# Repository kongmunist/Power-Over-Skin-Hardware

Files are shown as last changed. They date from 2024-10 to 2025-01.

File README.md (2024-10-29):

# Hi, welcome to the Power-over-Skin Repo

This repository contains the PCB files for the receiver board from the ACM UIST paper ["Power-over-Skin: Full-Body Wearables Powered By Intra-Body RF Energy"](https://dl.acm.org/doi/10.1145/3654777.3676394)

# BOM for receiver
You can assume all parts are generic unless mentioned below:

- R1-R7: Voltage setting resistors, should be 1% or better

- L2, L3: buck/boost inductors for the BQ25570. Should handle >200mA saturation current according to BQ25570 datasheet, but we're using low currents so you would probably get away with lower values. We used CB2518T100K and BRC2518T220K

- C4: Anything >100uF will do. I'm using the F950J107MPAAQ2, it is the only one that's quite so small, but it's also very DC-leaky

- L1: Should have a self-resonant frequency over 200 MHz in order to accomodate incoming square wave harmonics. 
- C9: Should be NP0, with a Vmax 10V or better

# Transmitter
In our experiments, we used a benchtop transmitter and a wearable one to generate 40 MHz square waves. These were passed through an impedance-matching network to couple into the body. The values we used were: first 20pF in series, then 820nH to ground. 

The 20pF should be NP0 with a voltage rating higher than the 40MHz you're sending into it. We used this inductor [(L-15FR82JV4E)](https://www.mouser.com/ProductDetail/Johanson-Technology/L-15FR82JV4E?qs=N%252Bgu1CRRfTPf9IhMOTDbHA%3D%3D) but anything with a self-resonant frequency >200 MHz should work. 

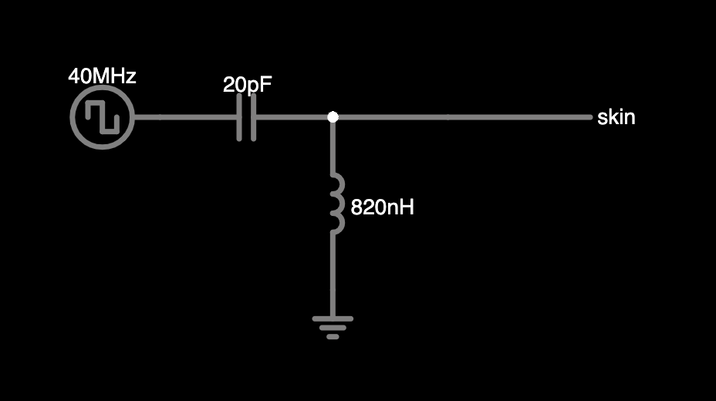
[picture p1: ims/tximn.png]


# Matching for other frequencies
The RF component values are all tuned for 40 MHz and human skin impedance — if you'd like to use another frequency, you'll have to resimulate the circuit. 

# Further questions?
Feel free to email Andy with any questions!

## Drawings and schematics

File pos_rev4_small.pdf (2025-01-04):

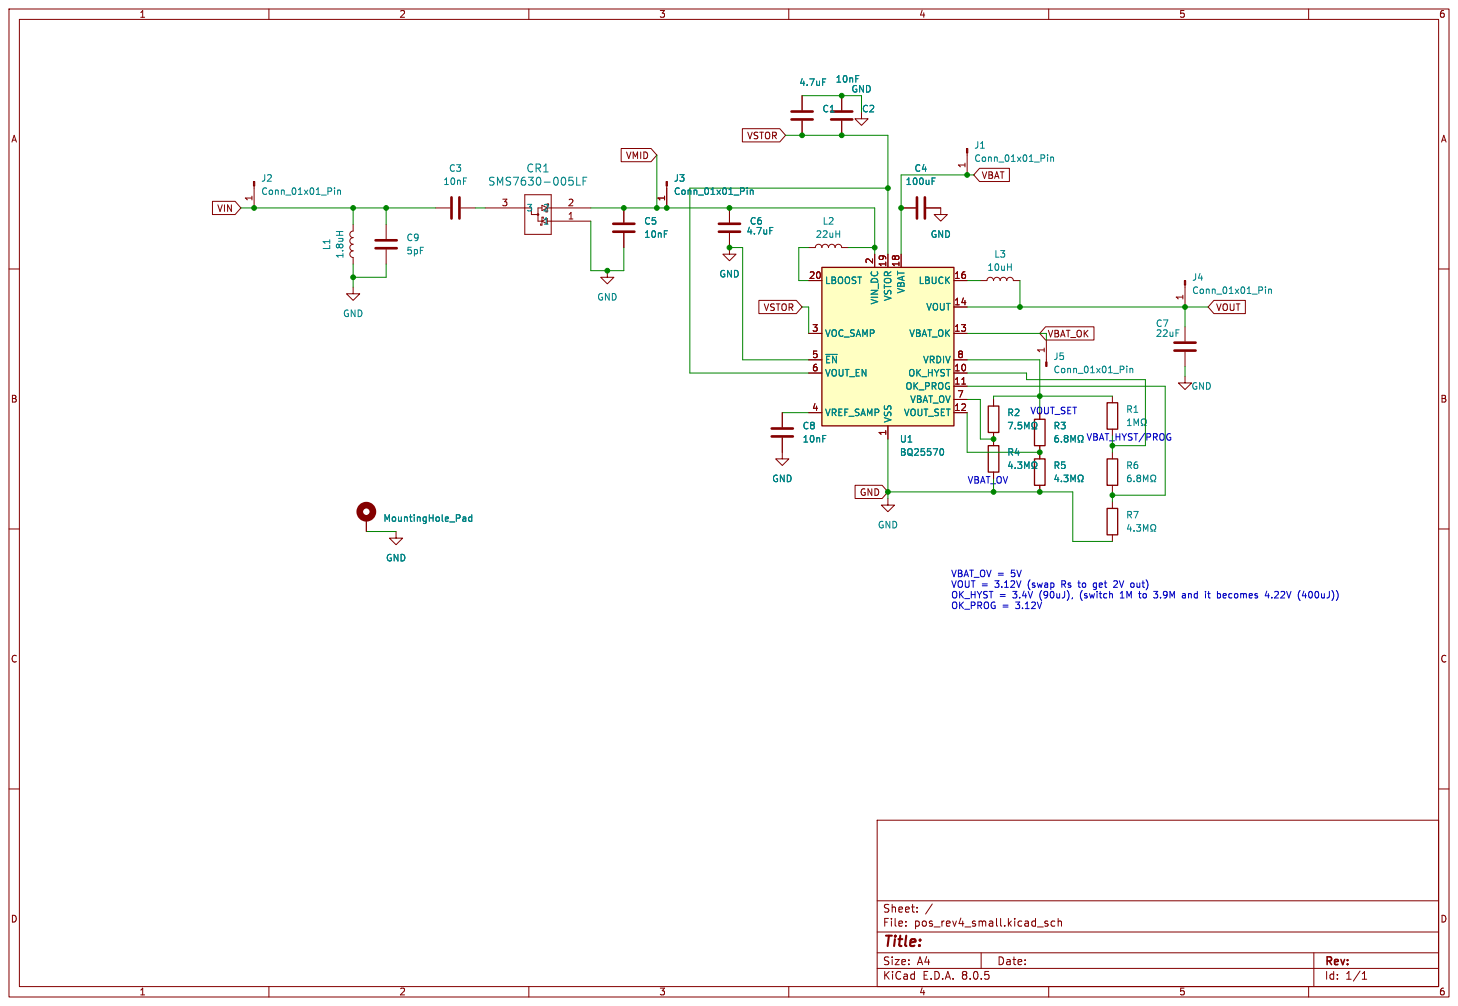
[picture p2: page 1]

Id: 1/1 Title: File: pos_rev4_small.kicad_sch Sheet: /

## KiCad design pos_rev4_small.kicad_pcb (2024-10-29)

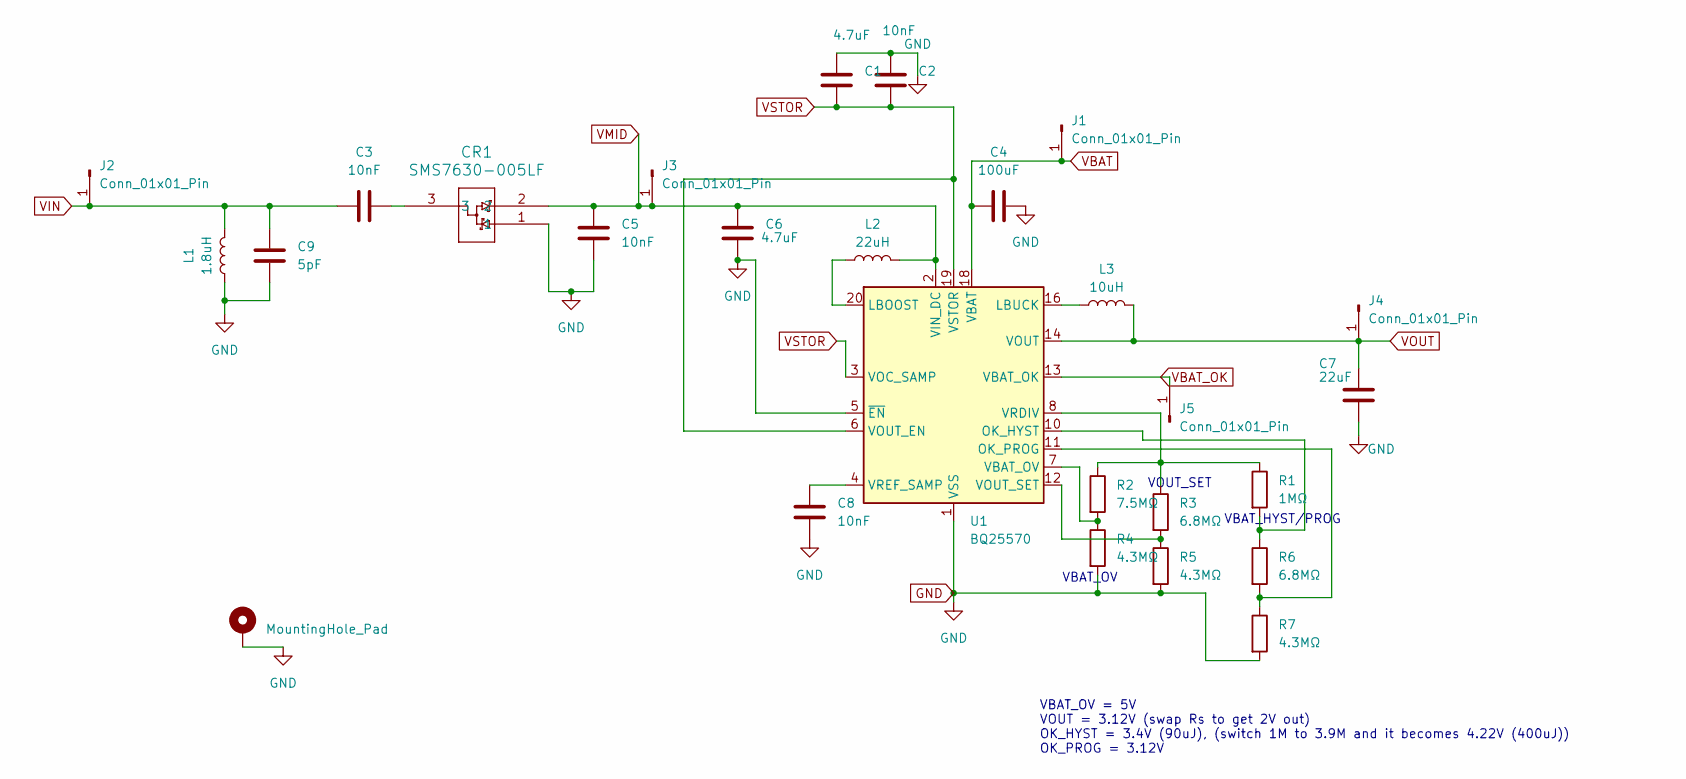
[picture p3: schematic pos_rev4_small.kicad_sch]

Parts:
C1, C6: 4.7uF; C_0402_1005Metric
C2, C3, C5, C8: 10nF; C_0402_1005Metric
C4: 100uF; C_0805_2012Metric
C7: 22uF; C_0603_1608Metric
C9: 5pF; C_0402_1005Metric
CR1: SMS7630-005LF; SOT-23_SKY
H1: MountingHole_Pad; TestPoint_Pad_D1.0mm
J1, J2, J3, J4, J5: Conn_01x01_Pin; TestPoint_Pad_D1.0mm
L1: 1.8uH; L_0805_2012Metric
L2: 22uH; L_1008_2520Metric
L3: 10uH; L_0805_2012Metric
R1: 1MΩ; R_0402_1005Metric
R2: 7.5MΩ; R_0402_1005Metric
R3, R6: 6.8MΩ; R_0402_1005Metric
R4, R5, R7: 4.3MΩ; R_0402_1005Metric
U1: BQ25570; QFN-20-1EP_3.5x3.5mm_P0.5mm_EP2x2mm

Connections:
GND: C1.1, C2.1, C4.2, C5.1, C6.2, C7.2, C8.2, C9.1, CR1.1, H1.1, L1.2, R4.2, R5.2, R7.2, U1.1 (VSS), U1.5 (~EN), U1.9 (VSS), U1.15 (VSS), U1.17 (VSS), U1.21 (VSS)
unnamed: C3.2, CR1.3
unnamed: L2.1, U1.20 (LBOOST)
unnamed: L3.1, U1.16 (LBUCK)
unnamed: R1.2, R6.1, U1.10 (OK_HYST)
unnamed: R6.2, R7.1, U1.11 (OK_PROG)
unnamed: R2.2, R4.1, U1.7 (VBAT_OV)
unnamed: R3.2, R5.1, U1.12 (VOUT_SET)
unnamed: R1.1, R2.1, R3.1, U1.8 (VRDIV)
unnamed: C8.1, U1.4 (VREF_SAMP)
VBAT: C4.1, J1.1, U1.18 (VBAT)
VBAT_OK: J5.1, U1.13 (VBAT_OK)
VIN: C3.1, C9.2, J2.1, L1.1
VMID: C5.2, C6.1, CR1.2, J3.1, L2.2, U1.2 (VIN_DC)
VOUT: C7.1, J4.1, L3.2, U1.14 (VOUT)
VSTOR: C1.2, C2.2, U1.3 (VOC_SAMP), U1.6 (VOUT_EN), U1.19 (VSTOR)

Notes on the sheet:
VOUT_SET
VBAT_HYST/PROG
VBAT_OV
VBAT_OV = 5V VOUT = 3.12V (swap Rs to get 2V out) OK_HYST = 3.4V (90uJ), (switch 1M to 3.9M and it becomes 4.22V (400uJ)) OK_PROG = 3.12V

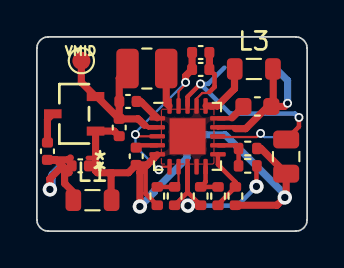
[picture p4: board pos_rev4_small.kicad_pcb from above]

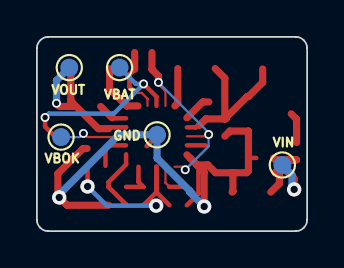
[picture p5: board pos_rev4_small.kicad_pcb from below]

Board: 2 copper layers, 15.0 x 10.8 mm, 27 parts (5 on the bottom side), 16 nets.
